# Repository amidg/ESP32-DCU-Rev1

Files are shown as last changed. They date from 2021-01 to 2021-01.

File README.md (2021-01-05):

# ESP32-DCU-Rev1
ROS-compatible ESP32 based Drive Control Unit (DCU) for DC motors. 
  Supports: 
    - Wi-Fi
    - Bluetooth
    - Ethernet (RJ45 via W5500)
    - Dual USB host (CH559L)
    - i2c encoders. 
    
Rev1 is designed to be super-simple and support main features required for the simple Arduino-like implementation of the advanced control for your ROS-based robot. 
If you are interested in PoE or EtherCAT functionality, please, refer to ESP32-DCU-Rev2 or ESP32-DCU-EtherCAT repositories in my Github. 

Manufacturing files are located in the "Manufacturing" folder as well as in the .zip archive.

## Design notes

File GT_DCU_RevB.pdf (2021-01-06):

# Gusev Tech ESP32-DCU-Rev1 Achitecture

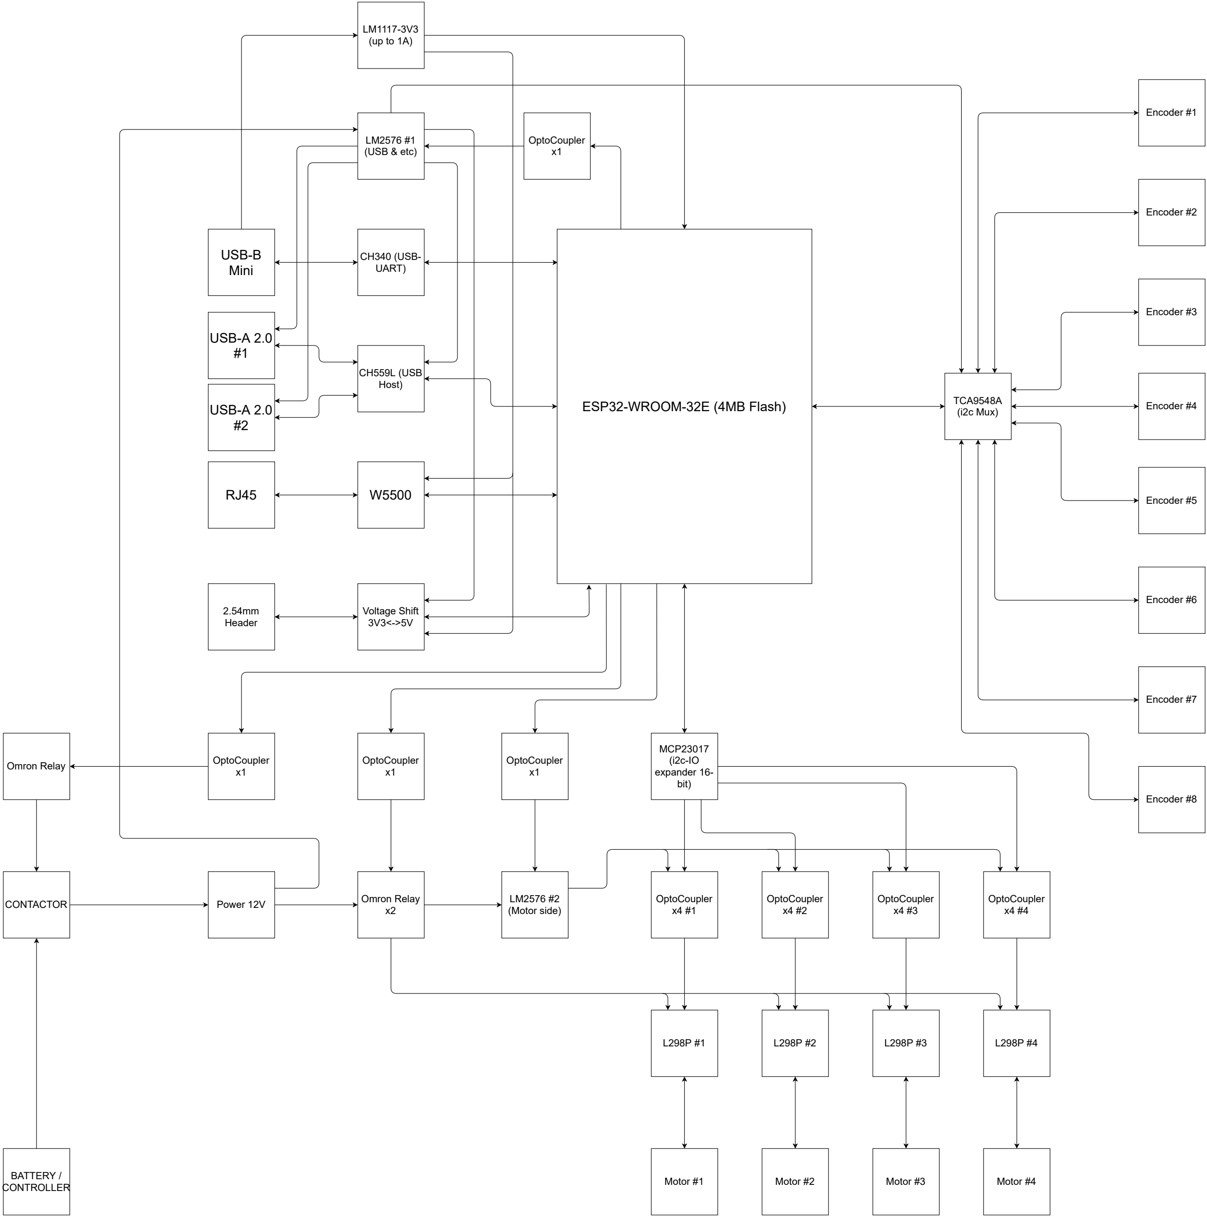
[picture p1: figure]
ESP32-WROOM-32E (4MB Flash); CH340 (USB- UART); USB-B Mini; USB-A 2.0 #1; CH559L (USB Host); USB-A 2.0 #2; TCA9548A (i2c Mux); Encoder #1; Encoder #2; Encoder #4; Encoder #3; Encoder #5; Encoder #6; Encoder #7; MCP23017 (i2c-IO expander 16- bit); Motor #1; Motor #2; Motor #3; Motor #4; Voltage Shift 3V3<->5V; 2.54mm Header; Power 12V; OptoCoupler x4 #1; OptoCoupler x4 #2; OptoCoupler x4 #3; OptoCoupler x4 #4; Omron Relay x2; OptoCoupler x1; LM2576 #2 (Motor side); Encoder #8; LM2576 #1 (USB & etc); OptoCoupler x1 Omron Relay; CONTACTOR; BATTERY / CONTROLLER

## DESIGN SPECIFICATIONS

1. Supports ONLY 12V input
2. ESP32 can be powered originally only via USB-B, power via 12V is possible if jumper applied
3. ESP32 and LV systems have separate ground GND_LV
4. HV systems have separate ground GND_HV
5. GND_LV and GND_HV can be connected via 0.05 ohm resistor of 1/10W to ensure it can be used as fuse
6. Powering Sequence: ESP32 (Type-C) -> 5V_LOW (on-board circuits that require 5V with digital signals) -> 5V_HIGH (on-board circuits that require high-power 5V) & 12V Main power to Motors

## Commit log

2021-01-05 Rev1 Architecture added
    [ESP32-DCU-Rev1.PrjPcb]
2021-01-05 Library updated
    [DCU1.SchDoc, DCU2.SchDoc, ESP32-DCU-Rev1.PcbLib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]
2021-01-05 USB-UART added
    [DCU1.SchDoc, ESP32.SchDoc, Ethernet.SchDoc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]
2021-01-06 ESP32 circuit is complete
    [CONN.SchDoc, DCU1.SchDoc, DCU2.SchDoc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]
2021-01-06 USB Host added
    [ESP32.SchDoc, USB-ESP32.SchDoc, USB-HOST.SchDoc]
2021-01-06 W5500 complete, finish up wiring for ESP32
    [ESP32.SchDoc, Ethernet.SchDoc, USB-HOST.SchDoc]
2021-01-11 CH340->FT231XS, ESP32 reworked, W5500 finished
    [CONN.SchDoc, ESP32.SchDoc, Ethernet.SchDoc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]
2021-01-11 MCP23017 is added
    [ESP32-DCU-Rev1.PrjPcb, Ethernet.SchDoc, MCP23017.SchDoc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]
2021-01-11 5V power rails are added
    [DCU1.SchDoc, ESP32-DCU-Rev1.PrjPcb, MCP23017.SchDoc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]
2021-01-11 relay circuits are added for Motor channels and contactor
    [DCU1.SchDoc, POWER.SchDoc, RELAYS.SchDoc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]
2021-01-11 5V-low-enable added as disable pin from esp32
    [RELAYS.SchDoc]
2021-01-11 5V-low-disable resistor fixed
    [RELAYS.SchDoc]
